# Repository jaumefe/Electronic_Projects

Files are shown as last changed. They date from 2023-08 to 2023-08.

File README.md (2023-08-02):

# Electronic_Projects
At this file, there will be included some electronic projects which could be used for home automation. Here, we can find the list of projects done until now:
* Weather Forecast Station

## Weather Forecast
It consists of a station which includes two sensors:
* SHT40-AD1B-R2: Temperature and Humidity Sensor
* DPS310: Barometric Pressure Sensor

This project only contains a board with both sensors which should be connected to a MCU by a I2C serial interface. In this case, I will be using a Raspberry Pi Pico to do the project. If you are also interested on the code, please check the following repository: https://github.com/jaumefe/Raspberry_Pico/tree/main/Weather_Forecast

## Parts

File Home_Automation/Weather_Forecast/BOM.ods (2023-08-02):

Parts | Qty | Value | Part Number 1 | Part Number 2 | Package | Description | Manufacturer 1 | Manufacturer 2
LED1 | 1 | Green | LL-S192UGC-1B | N/A | LED0603 | LED; SMD; 0603; green-yellow; 20÷40mcd; 1,6x0,8x0,6mm; 130°; 20mA | Luckylight | N/A
JP1 | 1 | 1x04 | DS1021-1*4SF11-B | 77311-101-04LF |  | Pin strip: pin; male; PIN: 4; straight; 2.54mm; THT; gold | Connfly | Amphenol
R5, R6, R7, R8 | 4 | 0R | 0603SAF0000T5E | CRCW06030000Z0TABC | R0603 | Resistor: thick film; SMD; 0603; 0Ω; 0,1W; ±1%; -55÷155°C | Royal Ohm | Vishay
C1, C2, C3 | 3 | 100nF / 10V | CL10A105KP8NNNC | 0603X105K100CT | C0603 | Capacitor: ceramic; MLCC; SMD; 0603; 100nF; 10V; X5R; ±10% | Samsung | Walsin
R3, R4 | 2 | 10k | 0603SAF1002T5E | RC0603FR-1310KL | R0603 | Resistor: thick film; SMD; 0603; 10kΩ; 0,1W; ±1%; -55÷155°C | Royal Ohm | Yageo
R1 | 1 | 330R | 0603SAF3300T5E | 1-2176339-9 | R0603 | Resistor: thick film; SMD; 0603; 330Ω; 0,1W; ±1%; -55÷155°C | Royal Ohm | TE Connectivity
U2 | 1 |  | DPS310 | N/A | LGA-8 | IC: Atmospheric pressure sensor; I2C; LGA-8 | Infineon | N/A
U1 | 1 |  | SHT40-AD1B-R2 | N/A | DFN-4 | IC: sensor; temperature and humidity; 0÷100%RH; -40÷125°C; DFN4 | Sensirion | N/A

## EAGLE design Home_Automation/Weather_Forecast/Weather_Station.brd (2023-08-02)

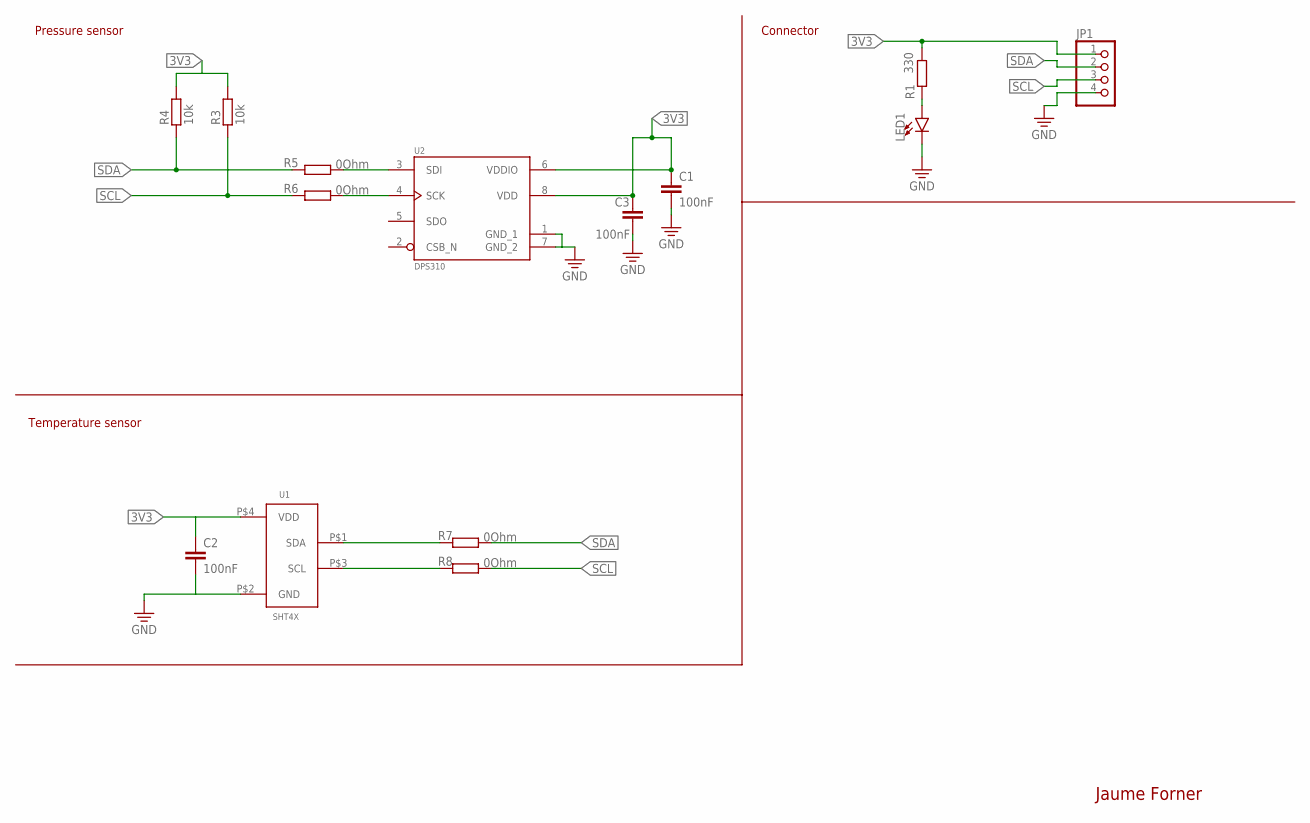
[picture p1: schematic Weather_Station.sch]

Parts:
C1, C2, C3: 100nF; C0603K
JP1: PINHD-1X4; 1X04
LED1: LED0603; LED-0603
R1: 330; R0603
R3, R4: 10k; R0603
R5, R6, R7, R8: 0Ohm; R0603
U1: SHT4X; SHT40-SHT41
U2: DPS310; LGA8S145X65P2X4_200X250X110-V

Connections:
3V3: C1.1, C2.1, C3.1, JP1.1, R1.1, R3.2, R4.2, U1.P$4 (VDD), U2.6 (VDDIO), U2.8 (VDD)
GND: C1.2, C2.2, C3.2, JP1.4, LED1.C, U1.P$2 (GND), U2.1 (GND_1), U2.7 (GND_2)
unnamed: R6.1, U2.4 (SCK)
unnamed: R5.1, U2.3 (SDI)
unnamed: R7.2, U1.P$1 (SDA)
unnamed: R8.2, U1.P$3 (SCL)
unnamed: LED1.A, R1.2
SCL: JP1.3, R3.1, R6.2, R8.1
SDA: JP1.2, R4.1, R5.2, R7.1

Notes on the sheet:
Jaume Forner
Pressure sensor
Temperature sensor
Connector

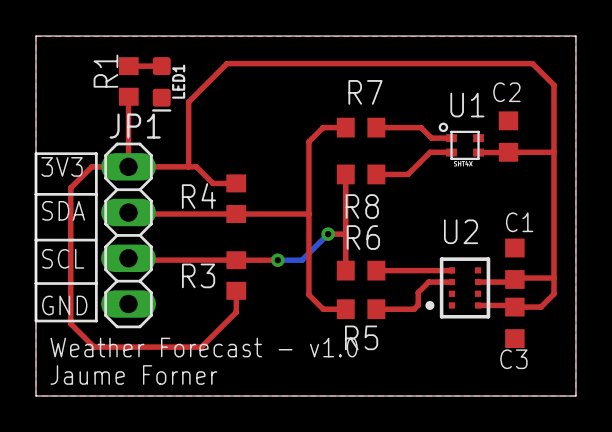
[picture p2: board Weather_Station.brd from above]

Board: 2 copper layers, 30.0 x 20.0 mm, 14 parts (0 on the bottom side), 9 nets.

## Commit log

2022-08-30 Weather Forecast Hardware Project. Design of schematic and PCB on Eagle
    [PnP_Weather_Station_fron.xlsx, PnP_Weather_Station_front.csv, Weather_Station.brd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]
2023-08-02 New version: Re-design for better working and added a LED for indicating power
    [BOM.ods, PnP_Weather_Station_fron.xlsx, PnP_Weather_Station_front.csv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]

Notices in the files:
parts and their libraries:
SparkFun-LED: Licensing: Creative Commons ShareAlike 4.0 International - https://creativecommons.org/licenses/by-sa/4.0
